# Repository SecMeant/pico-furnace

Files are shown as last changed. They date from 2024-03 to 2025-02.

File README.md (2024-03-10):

# pico-furnace
Raspberry PI pico wireless controller for electric furnace.

# Building

## Dependencies
 - [pico sdk](https://github.com/raspberrypi/pico-sdk) (tested on tag: 1.5.1)
 - [pico extras](https://github.com/raspberrypi/pico-extras) (tested on tag: sdk-1.5.1)

## Configure project options

Create `.config` with values for all CONFIG_* variables that user is intrested in changing.
User can also use one of the predefined config files from `configs/` by copying one of the files into `.config` file.
Configuring a project for the typical furnace target would look like:
```
cp configs/furnace .config
```
Make sure you always `make clean` after changing `.config` file to make sure new options are used to build the project.

## Configure wlan options

Create `wlan.ini` file and fill SSID and password of the WiFi network to which pico should connect when booting.
Example contents of the file:
```
ssid=my_wifi_network_name
pass=super_secret_password
```

## Configure and build

```console
export PICO_SDK_PATH=<path to pico sdk>
export PICO_EXTRAS_PATH=<path to pico extras>
make
```

## Flashing the binary

Connect pico W board USB while pressing the boot button and run:

```console
make flash
```

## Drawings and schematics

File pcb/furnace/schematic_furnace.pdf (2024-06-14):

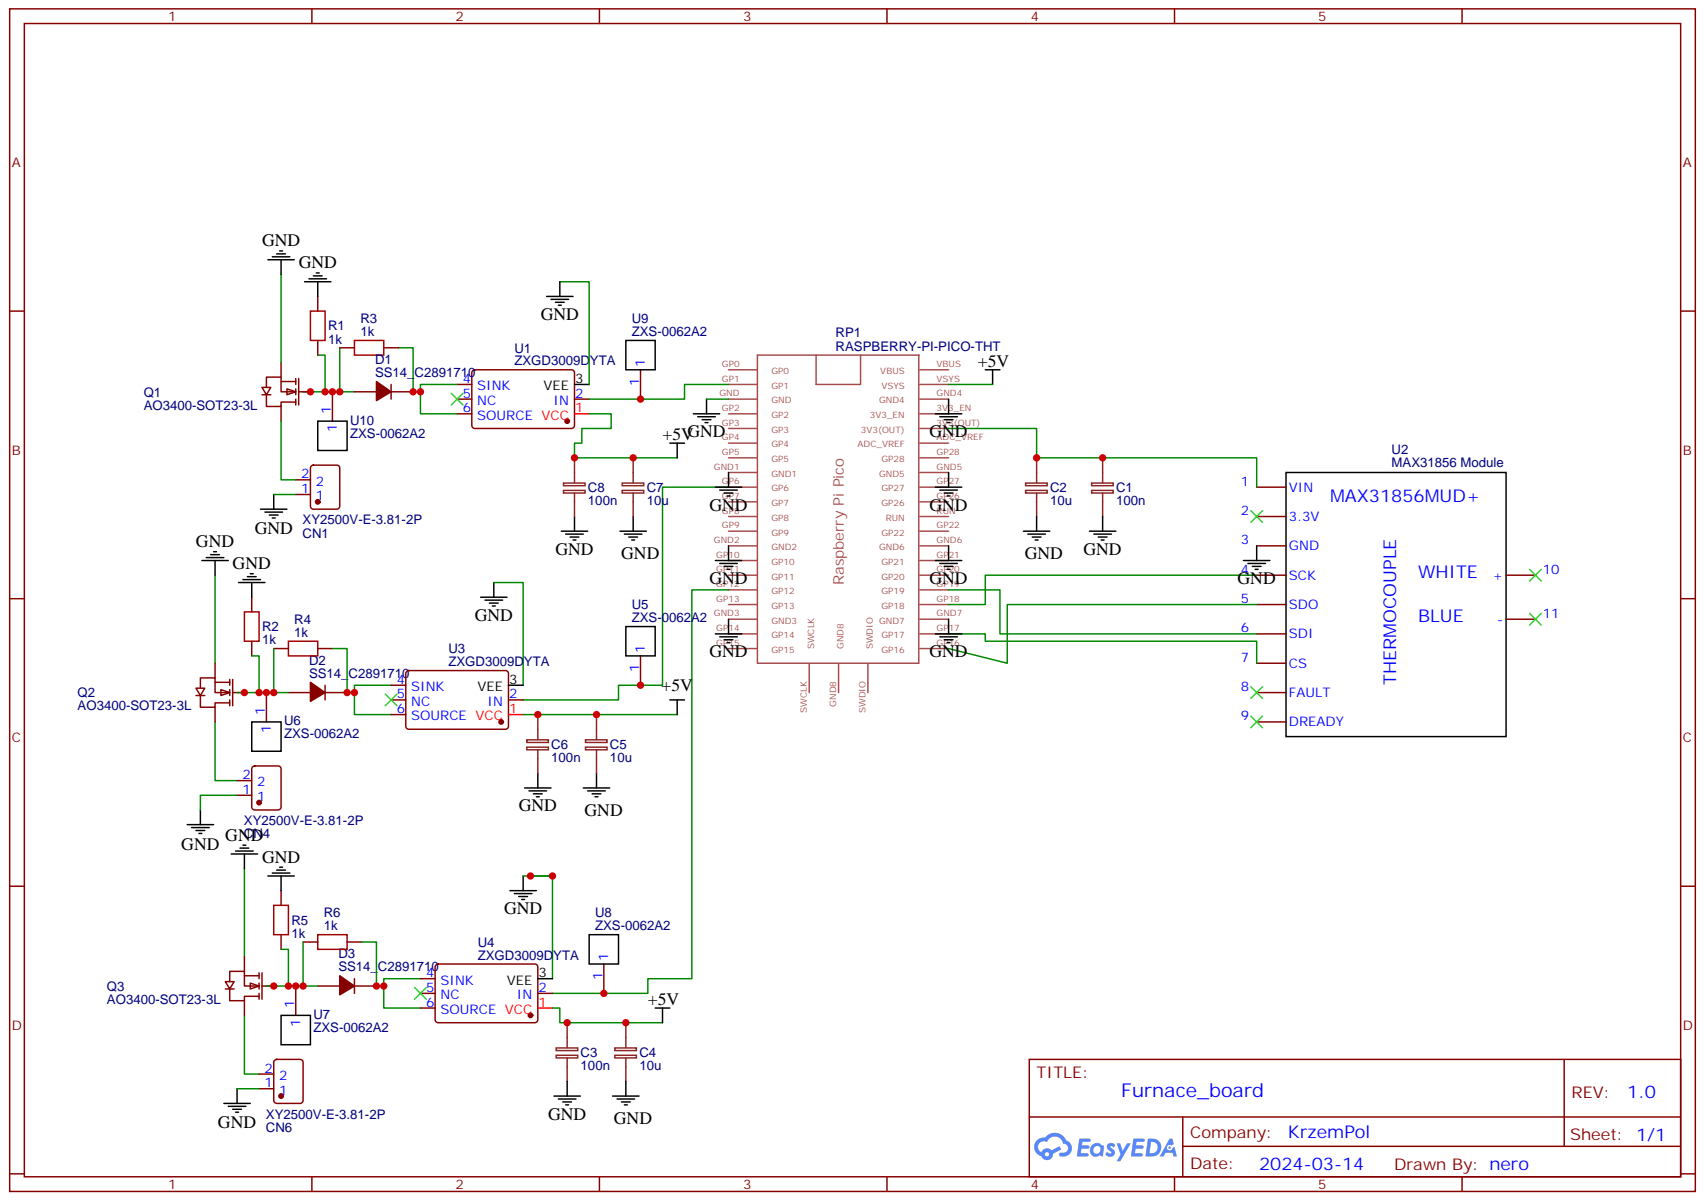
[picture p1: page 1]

RASPBERRY-PI-PICO-THT

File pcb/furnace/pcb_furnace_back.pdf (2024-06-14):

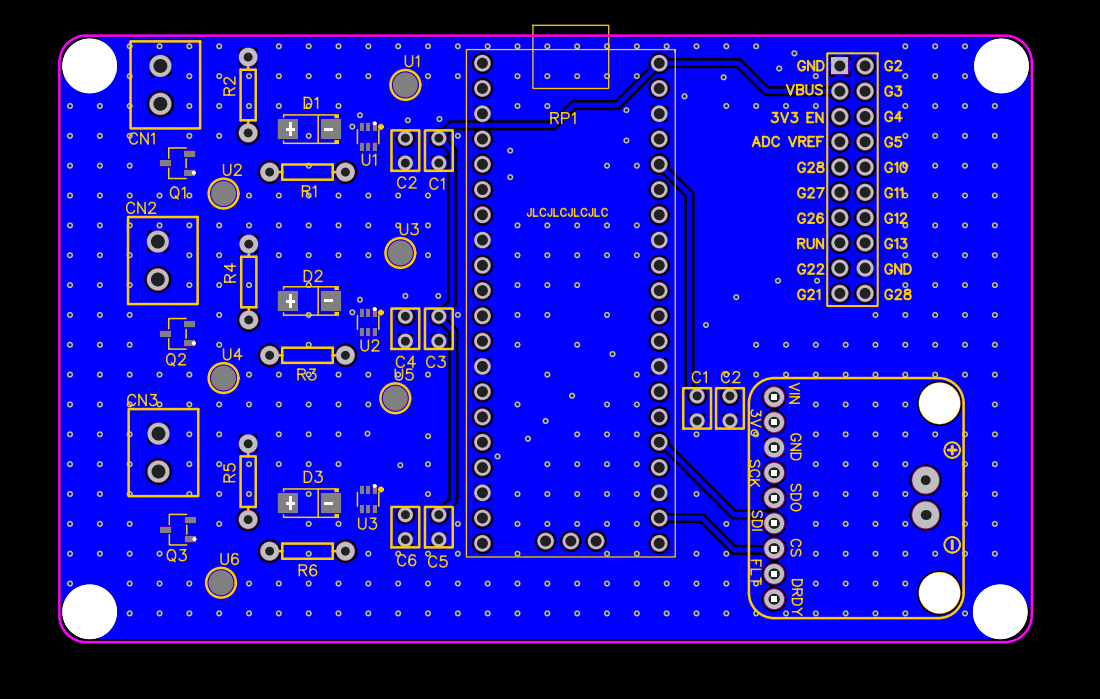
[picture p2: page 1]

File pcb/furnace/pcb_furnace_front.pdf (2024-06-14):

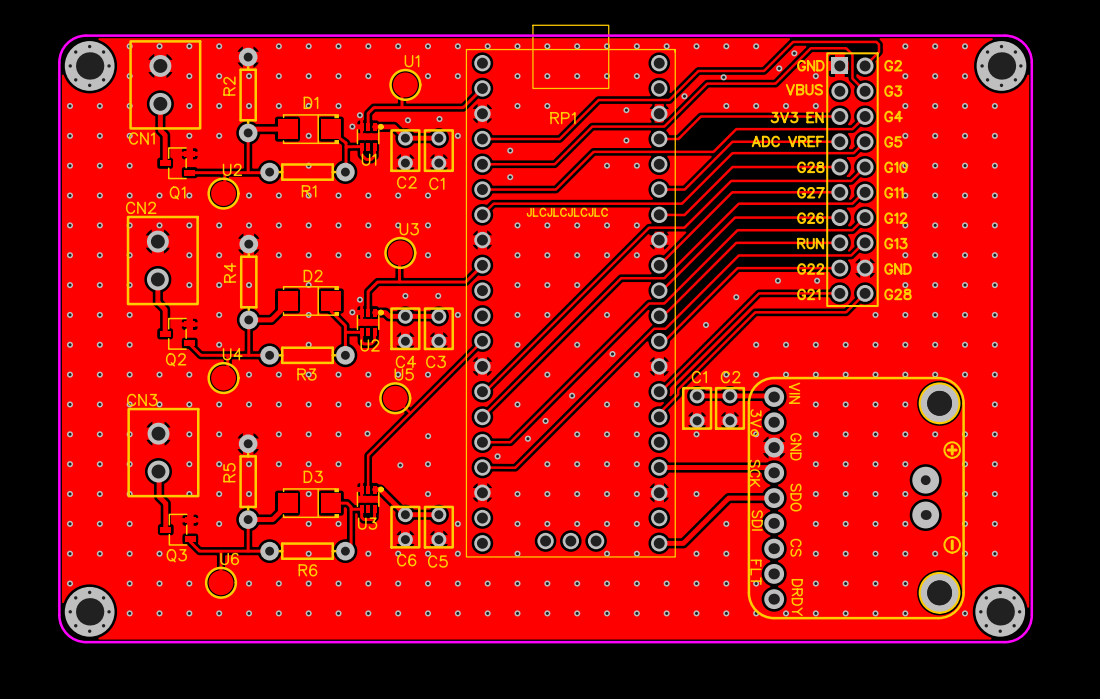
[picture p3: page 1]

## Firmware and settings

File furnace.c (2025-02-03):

#include <time.h>
#include <stdlib.h>
#include <string.h>

#include "pico/bootrom.h"
#include "pico/cyw43_arch.h"
#include "pico/stdlib.h"

#include "hardware/spi.h"

#include "lwip/pbuf.h"
#include "lwip/tcp.h"

#include "spi_config.h"
#if CONFIG_THERMO
  #include "max318xx.h"
#endif
#include "logger.h"

#if CONFIG_FLASH
  #include "flash_io.h"
#endif

#include "common.h"
#include CONSTEVAL_HEADER

#define TCP_PORT        4242
#define DEBUG_printf    printf


/* GPIO for enabling and disabling heating of the furnace. */
#define FURNACE_FIRE_PIN CONFIG_FURNACE_FIRE_PIN
#define FURNACE_FIRE_PWM_SLICE pwm_gpio_to_slice_num(FURNACE_FIRE_PIN)
#define FURNACE_FIRE_PWM_CHANNEL pwm_gpio_to_channel(FURNACE_FIRE_PIN)

#if CONFIG_SHUTTER
  #include "shutter.c"
#endif

#include "target.h"

#if CONFIG_WATER
  #define WATER_PIN 9
  #define WATER_PIN_SLICE pwm_gpio_to_slice_num(WATER_PIN)
#endif

#include "pwm.c"

#if CONFIG_MAGNETRON
  #include "magnetron.c"
#endif

int
max318xx_init(void);

static err_t
tcp_server_close(furnace_context_t* ctx)
{
  err_t err = ERR_OK;

  if (ctx->tcp.client_pcb != NULL) {
    tcp_arg(ctx->tcp.client_pcb, NULL);
    tcp_recv(ctx->tcp.client_pcb, NULL);
    tcp_err(ctx->tcp.client_pcb, NULL);
    err = tcp_close(ctx->tcp.client_pcb);

    if (err != ERR_OK) {
      log_stdout_server(ctx->log_bits, "close failed %d, calling abort\n", err);
      tcp_abort(ctx->tcp.client_pcb);
      err = ERR_ABRT;
    }

    ctx->tcp.client_pcb = NULL;
  }

  if (ctx->tcp.server_pcb) {
    tcp_arg(ctx->tcp.server_pcb, NULL);
    tcp_close(ctx->tcp.server_pcb);
    ctx->tcp.server_pcb = NULL;
  }

  return err;
}

static err_t
tcp_server_send_data(furnace_context_t* ctx,
                     struct tcp_pcb*    tpcb,
                     const uint8_t*     data,
                     u16_t              size)
{
  return tcp_write(tpcb, data, size, TCP_WRITE_FLAG_COPY);
}

static void
tcp_server_recv_(furnace_context_t *ctx, struct tcp_pcb* tpcb, struct pbuf* p)
{
  log_stdout_server(ctx->log_bits, "tcp_server_recv %d\n", p->tot_len);

  if (p->tot_len == 0)
    return;

  /*
   * Receive the buffer
   *
   * TODO: We should probably call pbuf_copy_partial in a loop
   *       to make sure we receive everything.
   */
  const uint16_t buffer_left = BUF_SIZE;
  ctx->tcp.recv_len =
    pbuf_copy_partial(p, ctx->tcp.recv_buffer, p->tot_len > buffer_left ? buffer_left : p->tot_len, 0);
  tcp_recved(tpcb, p->tot_len);
}

#if CONFIG_WATER
static void
handle_command_water(furnace_context_t* ctx, void (*feedback)(const char *, const size_t), unsigned arg) {
    const int res = set_pwm_safe(WATER_PIN, ctx, arg);

    if(res == 0)
      return;

    if (res  == 1){
      const char msg[] = "water pwm argument too big!\r\n";
      const size_t msg_len = sizeof(msg)-1;
      feedback(msg, msg_len);
      return;
    }

    if(res == -1){
      const char msg[] = "set_pwm_safe: unexpected pin argument!\r\n";
      const size_t msg_len = sizeof(msg)-1;
      feedback(msg, msg_len);
      return;
    }

    const char msg[] = "set_pwm_safe: unexpected return value!\r\n";
    const size_t msg_len = sizeof(msg)-1;
    feedback(msg, msg_len);
}
#endif

static int
set_max_pwm_safe(furnace_context_t *ctx, int new_max_pwm)
{
    if (new_max_pwm > MAX_PWM)
      return 1;

    if (ctx->pwm_level > new_max_pwm)
      ctx->pwm_level = new_max_pwm;

    ctx->ceiling_pwm = new_max_pwm;

    return 0;
}

#if CONFIG_STIRRER
static void
set_stirrer(bool opt)
{
  gpio_put(STIRRER_PIN, opt);
}
#endif

static void
command_handler(furnace_context_t* ctx, uint8_t* buffer, void (*feedback)(const char*, const size_t))
{
  unsigned arg;
  char     str_arg[BUF_SIZE];

  if (buffer[0] == '\n') return;

  if (memcmp(buffer, "reboot", 6) == 0) {
    reset_usb_boot(0,0);
  } else if (sscanf(buffer, "max_pwm %u", &arg) == 1) {
    const int res = set_max_pwm_safe(ctx, arg);
    if (res == 1) {
      const char msg[] = "pwm argument too big!\r\n";
      const size_t msg_len = sizeof(msg)-1;
      feedback(msg, msg_len);
    }
  } else if (strncmp(buffer, "pwm\n", 4) == 0) {
      char msg[16];
      const size_t msg_len = snprintf(msg, sizeof(msg), "pwm = %d\r\n", ctx->pwm_level);
      feedback(msg, msg_len);
  } else if (sscanf(buffer, "pwm %u", &arg) == 1) {
    const int res= set_pwm_safe(FURNACE_FIRE_PIN, ctx, arg);
    if (res == 0){
#if CONFIG_AUTO == CONFIG_AUTO_PILOT || CONFIG_AUTO == CONFIG_AUTO_MAPPER
      ctx->pilot.is_enabled = 0;
#endif
    } else if ( res == 1){
      const char msg[] = "pwm argument too big!\r\n";
      const size_t msg_len = sizeof(msg)-1;
      feedback(msg, msg_len);
    } else if ( res == -1){
      const char msg[] = "set_pwm_safe: unexpected pin argument!\r\n";
      const size_t msg_len = sizeof(msg)-1;
      feedback(msg, msg_len);
    } else {
      const char msg[] = "set_pwm_safe: unexpected return value!\r\n";
      const size_t msg_len = sizeof(msg)-1;
      feedback(msg, msg_len);
    }
  }
#if CONFIG_AUTO == CONFIG_AUTO_PILOT
  else if (strncmp(buffer, "auto\n", 5) == 0) {
      char msg[16];
      const size_t msg_len = snprintf(msg, sizeof(msg), "auto = %d\r\n", ctx->pilot.is_enabled);
      feedback(msg, msg_len);
  } else if (sscanf(buffer, "auto %u", &arg) == 1) {
    if (arg > 1) {
      const char msg[] = "auto argument needs to be 0 or 1\r\n";
      const size_t msg_len = sizeof(msg)-1;
      feedback(msg, msg_len);
    } else {
      ctx->pilot.is_enabled = arg;
    }
  } else if (sscanf(buffer, "temp %u", &arg) == 1) {
    if (arg > MAX_TEMP) {
      const char msg[] = "temp argument too big!\r\n";
      const size_t msg_len = sizeof(msg)-1;
      feedback(msg, msg_len);
    } else {
      ctx->pilot.des_temp = arg;
    }
  } else if (strncmp(buffer, "temp\n", 5) == 0) {
    char msg[16];
    const size_t msg_len = snprintf(msg, sizeof(msg), "temp = %d\r\n", ctx->pilot.des_temp);
    feedback(msg, msg_len);
  }
#endif
  else if (sscanf(buffer, "log %" STR(BUF_SIZE) "s %u", &str_arg, &arg) == 2) {
    if(arg >= 2) {
      const char msg[] = "log value too big!\r\n";
      const size_t msg_len = sizeof(msg)-1;
      feedback(msg, msg_len);
    } else {
      set_log(str_arg, arg, &ctx->log_bits);
    }
  } else if (strncmp(buffer, "log\n", 4) == 0) {
    char msg[LOG_MSG_BUFFER_SIZE];
    const size_t msg_len = get_logs(msg, ctx->log_bits);
    feedback(msg, msg_len);
  } else if(memcmp(buffer, "help\n", 5) == 0) {

    const char msg[] = "help              \t\t shows this message\n"
                        "reboot            \t\t reboot device\n"
                        "pwm <0;50>        \t\t sets pwm\n"
                        "pwm               \t\t prints current pwm level\n"
                        "max_pwm <0;50>    \t\t sets max pwm level.\n"
                        "                  \t\t\t Device will never exceed this pwm value\n"
#if CONFIG_THERMO && CONFIG_AUTO == CONFIG_AUTO_PILOT
                        "temp <0;" STR(MAX_TEMP) ">     \t\t sets wanted temperature\n"
                        "temp              \t\t shows current wanted temperature\n"
                        "auto <0;1>        \t\t sets automatic pwm control, it is\n"
                        "                  \t\t reaching temperature set by 'temp' command\n"
                        "                  \t\t\t 0 - off\n"
                        "                  \t\t\t 1 - on\n"
                        "auto              \t\t shows current auto status\n"
#endif
#if CONFIG_MAGNETRON
                        "pulse <0:127>     \t\t starts pulses of magnetron\n"
#endif
#if CONFIG_WATER
                        "water <0:10>      \t\t sets pwm duty of water channel\n"
                        "water             \t\t shows current water pwm\n"
#endif
#if CONFIG_AUTO == CONFIG_AUTO_MAPPER
                        "map <0;1>         \t\t sets automatic pwm mapping, it is\n"
                        "                  \t\t checking max temperature on every pwm\n"
                        "                  \t\t\t 0 - off\n"
                        "                  \t\t\t 1 - on\n"
                        "map               \t\t shows current map status\n"
#endif
#if CONFIG_STIRRER
                        "stir <0;1>        \t\t turns on the stirring cap for beaker\n"
                        "                  \t\t\t 0 - off\n"
                        "                  \t\t\t 1 - on\n"
#endif
                        "log <option> <0;1>\t\t sets output level on stdio\n"
                        "                  \t\t\t options:\n"
                        "                  \t\t\t\t server,\n"
                        "                  \t\t\t\t thermocouple,\n"
                        "                  \t\t\t\t basic\n"
                        "                  \t\t\t 0 - off\n"
                        "                  \t\t\t 1 - on\n"
                        "log               \t\t prints names of turned on log options\n";
    const size_t msg_len = sizeof(msg)-1;
    feedback(msg, msg_len);
  }
#if CONFIG_MAGNETRON
  else if(sscanf(buffer, "pulse %u", &arg) == 1) {
    if(arg > 127){
      const char msg[] = "pulse value too big!\r\n";
      const size_t msg_len = sizeof(msg)-1;
      feedback(msg, msg_len);
    } else {
      ctx->pulse_count = arg*2;
    }
  }
#endif
#if CONFIG_WATER
  else if(sscanf(buffer, "water %u", &arg) == 1) {
    handle_command_water(ctx, feedback, arg);
  } else if(memcmp(buffer, "water\n", 6) == 0){
    char msg[16];
    const size_t msg_len = snprintf(msg, sizeof(msg), "water = %d\r\n", ctx->pwm_water);
    feedback(msg, msg_len);
  }
#endif
#if CONFIG_SHUTTER
  else if(sscanf(buffer, "shutter %u", &arg) == 1){
    if(arg > MAX_SHUTTER_MS){
      const char msg[] = "time argument too big !!!\r\n";
      const size_t msg_len = sizeof(msg)-1;
      feedback(msg, msg_len);
    } else if(ctx->shutter.time_ms == 0){
      ctx->shutter.time_ms = arg;
    } else{
      const char msg[] = "shutter already in work \n";
      const size_t msg_len = sizeof(msg)-1;
      feedback(msg, msg_len);
    }
  } else if(sscanf(buffer, "shutter %s", str_arg) == 1) {
    if(strncmp(str_arg, "on", 2) == 0){
      ctx->shutter.time_ms = 1;
      ctx->shutter.intern_state = SHUTTER_ON_OPTION;
    }else if((strncmp(str_arg, "off", 3) == 0)){
      ctx->shutter.time_ms = 1;
      ctx->shutter.intern_state = SHUTTER_OFF_OPTION;
    }
  }
#endif
#if CONFIG_AUTO == CONFIG_AUTO_MAPPER
  else if(sscanf(buffer, "map %u", &arg) == 1) {
    if(arg > 1){
      const char msg[] = "map argument needs to be 0 or 1\r\n";
      const size_t msg_len = sizeof(msg)-1;
      feedback(msg, msg_len);
    } else {
      if(ctx->cur_temp >= 40){
        const char msg[] = "map can be started only at temperatures lower than 40\r\n";
        const size_t msg_len = sizeof(msg)-1;
        feedback(msg, msg_len);
      } else {
        ctx->pwm_level = 0;
        ctx->pilot.is_enabled = false;
        ctx->mapper.is_enabled = arg;
      }
    }
  } else if(strncmp(buffer, "map\n", 4) == 0) {
      char msg[16];
      const size_t msg_len = snprintf(msg, sizeof(msg), "map = %d\r\n", ctx->mapper.is_enabled);
      feedback(msg, msg_len);
  }
#endif
#if CONFIG_STIRRER
  else if(sscanf(buffer, "stir %u", &arg) == 1){
    if(arg > 1){
      const char msg[] = "stir argument needs to be 0 or 1\r\n";
      const size_t msg_len = sizeof(msg)-1;
      feedback(msg, msg_len);
    } else {
      set_stirrer((bool) arg);
    }
  }
#endif
}

static void
tcp_command_handler(furnace_context_t* ctx, struct tcp_pcb* tpcb)
{
  void
  send(const char* msg, const size_t msg_len)
  {
    tcp_server_send_data(ctx, tpcb, msg, msg_len);
  }

  command_handler(ctx, ctx->tcp.recv_buffer, &send);
}

static err_t
tcp_server_recv(void* ctx_, struct tcp_pcb* tpcb, struct pbuf* p, err_t err)
{
  furnace_context_t *ctx = (furnace_context_t*)ctx_;

  if (!p) {
    tcp_server_close(ctx);
    return err;
  }

  tcp_server_recv_(ctx, tpcb, p);
  //We are expecting only strings, we can manually terminate the string
  ctx->tcp.recv_buffer[p->tot_len] = '\0';

  pbuf_free(p);

  // Echo back for debugging
  // tcp_server_send_data(ctx, tpcb, ctx->recv_buffer, ctx->recv_len);

  tcp_command_handler(ctx, tpcb);

  log_stdout_server(ctx->log_bits, "tcp_server_recv: %.*s\n", p->tot_len, ctx->tcp.recv_buffer);

  return ERR_OK;
}

static void
tcp_server_err(void* ctx_, err_t err)
{
  furnace_context_t *ctx = (furnace_context_t*)ctx_;

  log_stdout_server(ctx->log_bits, "tcp_client_err_fn %d\n", err);
  tcp_server_close(ctx);
}

static err_t
tcp_server_accept(void* ctx_, struct tcp_pcb* client_pcb, err_t err)
{
  furnace_context_t *ctx = (furnace_context_t*)ctx_;

  if (err != ERR_OK || client_pcb == NULL) {
    log_stdout_server(ctx->log_bits, "Failure in accept\n");
    tcp_server_close(ctx);
    return ERR_VAL;
  }

  log_stdout_server(ctx->log_bits, "Client connected\n");

  ctx->tcp.client_pcb = client_pcb;
  tcp_arg(client_pcb, ctx);
  tcp_recv(client_pcb, tcp_server_recv);
  tcp_err(client_pcb, tcp_server_err);

  client_pcb->so_options |= SOF_KEEPALIVE;
  client_pcb->keep_intvl = 4000; /* 4 seconds */

  return ERR_OK;
}

static bool
tcp_server_open(void* ctx_)
{
  furnace_context_t *ctx = (furnace_context_t*)ctx_;

  log_stdout_server(ctx->log_bits,
                     "Starting server at %s on port %u\n",
                     ip4addr_ntoa(netif_ip4_addr(netif_list)),
                     TCP_PORT);

  struct tcp_pcb* pcb = tcp_new_ip_type(IPADDR_TYPE_ANY);
  if (!pcb) {
    log_stdout_server(ctx->log_bits, "Failed to create pcb\n");
    return false;
  }

  err_t err = tcp_bind(pcb, NULL, TCP_PORT);
  if (err) {
    log_stdout_server(ctx->log_bits, "Failed to bind to port %u\n", TCP_PORT);
    return false;
  }

  ctx->tcp.server_pcb = tcp_listen_with_backlog(pcb, 1);
  if (!ctx->tcp.server_pcb) {
    log_stdout_server(ctx->log_bits, "Failed to listen\n");
    if (pcb) {
      tcp_close(pcb);
    }
    return false;
  }

  tcp_arg(ctx->tcp.server_pcb, ctx);
  tcp_accept(ctx->tcp.server_pcb, tcp_server_accept);

  return true;
}

static void
do_thermocouple_work(furnace_context_t *ctx, bool deadline_met)
{
  if (!deadline_met)
    return;

#if CONFIG_THERMO
  ctx->cur_temp = max318xx_read_temperature();
#endif
#if CONFIG_THERMO == CONFIG_THERMO_KTYPE
  log_stdout_thermocouple(ctx->log_bits, "cold: %u\n", max318xx_read_cold_junction());
#endif
  log_stdout_thermocouple(ctx->log_bits, "hot: %u\n", ctx->cur_temp);
}

static int
format_status(char* buffer, furnace_context_t* ctx)
{
#if CONFIG_AUTO == CONFIG_AUTO_NONE
  return snprintf(
      buffer,
      FORMAT_STATUS_AUTO_NONE_SIZE,
      FORMAT_STATUS_AUTO_NONE,
      ctx->cur_temp,
      ctx->pwm_level,
      MAX_PWM
      );
#else
    return snprintf(
      buffer,
      FORMAT_STATUS_AUTO_PILOT_SIZE,
      FORMAT_STATUS_FMT,
      ctx->cur_temp,
      ctx->pilot.des_temp,
      ctx->pwm_level,
      ctx->ceiling_pwm,
      MAX_PWM,
      ctx->pilot.is_enabled
    );
#endif
}

#if CONFIG_AUTO == CONFIG_AUTO_MAPPER

static int
format_mapper(char *buffer, furnace_context_t *ctx)
{
    return snprintf(
      buffer,
      MAPPER_STATUS_SIZE,
      MAPPER_STATUS_FMT,
      ctx->pwm_level,
      ctx->mapper.max_pwm_temp
    );
}

#endif

static void
do_tcp_work(furnace_context_t *ctx, bool deadline_met)
{
#if CONFIG_AUTO == CONFIG_AUTO_NONE
  char temperature_str[FORMAT_STATUS_AUTO_NONE_SIZE];
#else
  char temperature_str[FORMAT_STATUS_AUTO_PILOT_SIZE];
#endif

  cyw43_arch_poll();

  // If disconnected, reset and setup listening
  if (ctx->tcp.server_pcb == NULL || ctx->tcp.server_pcb->state == CLOSED) {
    memset(&ctx->tcp, 0, sizeof(ctx->tcp));
    if (!tcp_server_open(ctx)) {
      tcp_server_close(ctx);
    }
  }

  if (ctx->tcp.client_pcb && deadline_met) {
    const int temperature_str_len = format_status(temperature_str, ctx);

    tcp_server_send_data(
      ctx,
      ctx->tcp.client_pcb,
      (uint8_t*)temperature_str,
      temperature_str_len
    );
  }

}

static inline int
sgn(int val_1, int val_2)
{
  if(val_1 > val_2)
    return -1;
  return 1;
}

static inline uint8_t
clamp_u8(int min, int max, int val)
{
  uint8_t value = (uint8_t)val;

  if(val < min)
    value = min;

  if(val > max)
    value = max;

  return value;
}

static void
init_furnace(furnace_context_t *ctx)
{
  memset(ctx, 0, sizeof(*ctx));

  ctx->ceiling_pwm = MAX_PWM;
}

#if CONFIG_AUTO == CONFIG_AUTO_PILOT || CONFIG_AUTO == CONFIG_AUTO_MAPPER
static void
do_pilot_work(furnace_context_t *ctx)
{
  if (!ctx->pilot.is_enabled)
    return;

  const bool deadline_met = get_absolute_time() > ctx->pilot.pilot_deadline;

  if (!deadline_met)
    return;

  const int min_increase_rate = 1;
  const int diff = ctx->cur_temp - ctx->pilot.last_temp;
  const int sign = sgn(ctx->cur_temp, ctx->pilot.des_temp);
  unsigned pwm = ctx->pwm_level;

  ctx->pilot.last_temp = ctx->cur_temp;
  ctx->pilot.pilot_deadline = make_timeout_time_ms(CONFIG_FURNACE_DEADLINE_MS);

  /*
   * If going in the wrong direction
   * or going in the good direction,
   * but slowly - nudge the PWM.
   */
  if(sign*diff <= min_increase_rate)
    pwm += sign;

  set_pwm_safe(FURNACE_FIRE_PIN, ctx, pwm);
}

static void
init_pilot(furnace_context_t *ctx)
{
  ctx->pilot.des_temp = 0;
  ctx->pilot.last_temp = 0;
  ctx->pilot.is_enabled = false;
}
#endif

#if CONFIG_STIRRER
static void
init_stirrer(void)
{
  gpio_init(STIRRER_PIN);
  gpio_set_dir(STIRRER_PIN, GPIO_OUT);
}
#endif

static void
init_stdio(furnace_context_t* ctx)
{
  ctx->stdio.parser = ctx->stdio.buffer;
  memset(&ctx->stdio.buffer, 0, BUF_SIZE);
}

static void
reset_stdio_data(furnace_context_t* ctx)
{
  memset(&ctx->stdio.buffer, 0, BUF_SIZE);
  ctx->stdio.parser = ctx->stdio.buffer;
}

static void
stdio_command_handler(furnace_context_t* ctx)
{
  void
  send_stdio(const char* msg, const size_t msg_len)
  {
    if(msg_len == 0) return;
    printf(msg);
  }

  command_handler(ctx, ctx->stdio.buffer, &send_stdio);
}

static void
do_stdio_work(furnace_context_t* ctx, bool deadline_met)
{
  if(deadline_met)
  {
    char buffer[FORMAT_STATUS_AUTO_PILOT_SIZE];

    format_status(buffer, ctx);
    log_stdout_basic(ctx->log_bits, buffer);
  }

  while(1) {
    uint8_t c = getchar_timeout_us(0);

    if(c == (uint8_t) PICO_ERROR_TIMEOUT) return;

    if(ctx->stdio.parser == ctx->stdio.buffer + BUF_SIZE){
      printf("\nLines longer than %d are invalid!\nResetting stdio buffer.\n", BUF_SIZE);
      reset_stdio_data(ctx);
      return;
    }

    // User may change last sent character from lf to cr, vice versa or crlf
    // Although, in parsing command, we do not care how user sent this
    // and we are always putting '\n' at the end of command
    if(c == '\n' || c == '\r') {
      *ctx->stdio.parser = '\n';
      stdio_command_handler(ctx);
      reset_stdio_data(ctx);
      return;
    }

    *ctx->stdio.parser = c;
    ctx->stdio.parser++;
  }
}

#if CONFIG_AUTO == CONFIG_AUTO_MAPPER

static void
mapper_deadline__(furnace_context_t *ctx)
{
  if(ctx->cur_temp > ctx->mapper.max_pwm_temp){
    ctx->mapper.max_pwm_temp = ctx->cur_temp;
    return;
  }

  char buffer[MAPPER_STATUS_SIZE];

  const int size = format_mapper(buffer, ctx);
  tcp_server_send_data(
    ctx,
    ctx->tcp.client_pcb,
    (uint8_t*)buffer,
    size
  );

  const unsigned pwm = ctx->pwm_level + 1;

  const int res = set_pwm_safe(FURNACE_FIRE_PIN, ctx, pwm);

  if( res == -1 ) {
    const char msg[] = "set_pwm_safe: unexpected pin argument!\r\n";
    const size_t msg_len = sizeof(msg)-1;
    tcp_server_send_data(
      ctx,
      ctx->tcp.client_pcb,
      (uint8_t*)buffer,
      size
    );
  } else if ( res == 1 ) {
    const char msg[] = "pwm_level has reached MAX_PWM, enabling auto and steering temp towards FALLBACK_TEMP!\r\n";
    const size_t msg_len = sizeof(msg)-1;
    tcp_server_send_data(
      ctx,
      ctx->tcp.client_pcb,
      (uint8_t*)buffer,
      size
    );

    ctx->mapper.is_enabled = false;
    ctx->pilot.is_enabled = true;
    ctx->pilot.des_temp = FALLBACK_TEMP;
  }
}

static void
mapper_deadline_(furnace_context_t *ctx)
{
  mapper_deadline__(ctx);
  ctx->mapper.deadline = make_timeout_time_ms(PWM_MAPPER_MINUTES * 60 * 1000);
}

static void
mapper_maxtemp_reached_(furnace_context_t *ctx)
{
  const char msg[] = "cur_temp has reached MAX_TEMP, enabling auto and steering temp towards FALLBACK_TEMP!\r\n";
  const size_t msg_len = sizeof(msg)-1;
  tcp_server_send_data(
    ctx,
    ctx->tcp.client_pcb,
    (uint8_t*)msg,
    msg_len
  );

  ctx->mapper.is_enabled = false;
  ctx->pilot.is_enabled = true;
  ctx->pilot.des_temp = FALLBACK_TEMP;
}

static void
do_mapper_work(furnace_context_t *ctx)
{
  if(!ctx->mapper.is_enabled)
    return;

  if(ctx->cur_temp >= MAX_TEMP)
    return mapper_maxtemp_reached_(ctx);

  const bool deadline_met = get_absolute_time() > ctx->mapper.deadline;
  if (deadline_met)
    return mapper_deadline_(ctx);
}

#endif

static int
main_work_loop(void)
{
  furnace_context_t* ctx;

  ctx = malloc(sizeof(*ctx));

  if (!ctx) {
    return 1;
  }

  init_pwm();
  init_furnace(ctx);
#if CONFIG_AUTO == CONFIG_AUTO_MAPPER || CONFIG_AUTO == CONFIG_AUTO_PILOT
  init_pilot(ctx);
#endif
  init_stdio(ctx);

#if CONFIG_MAGNETRON
  init_magnetron(ctx);
#endif

#if CONFIG_STIRRER
  init_stirrer();
#endif

#if CONFIG_FLASH
  init_flash(ctx);
#endif

  cyw43_arch_gpio_put(CYW43_WL_GPIO_LED_PIN, 1);

  while (1) {
    const absolute_time_t now = get_absolute_time();
    const bool deadline_met = now > ctx->update_deadline;
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
int
main(void)
{
  stdio_init_all();

  if (cyw43_arch_init()) {
    DEBUG_printf("failed to initialise\n");
    return 1;
  }

  cyw43_arch_gpio_put(CYW43_WL_GPIO_LED_PIN, 0);
  cyw43_arch_enable_sta_mode();

  while(1) {
    int ret = main_();

    if (ret)
      DEBUG_printf("main() failed with %d\n", ret);

    sleep_ms(3000);
  }
}

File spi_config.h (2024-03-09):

#pragma once

#define FURNACE_SPI_RX_PIN    16
#define FURNACE_SPI_CSN_PIN   17
#define FURNACE_SPI_SCK_PIN   18
#define FURNACE_SPI_TX_PIN    19

#define FURNACE_SPI_INSTANCE spi0

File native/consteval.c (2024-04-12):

#include <stdio.h>

#include "common.h"

static void
prepare(FILE* fptr)
{
  fprintf(fptr, "#pragma once\n\n");
}

static void
calculate_status_size(FILE* fptr)
{
  const size_t size = snprintf(0, 0, FORMAT_STATUS_FMT, MAX_TEMP, MAX_TEMP, MAX_PWM, MAX_PWM, MAX_PWM, MAX_AUTO) + 1;
  fprintf(fptr, "#define FORMAT_STATUS_AUTO_PILOT_SIZE %u\n", size);
}

#if CONFIG_AUTO == CONFIG_AUTO_MAPPER
static void
calculate_mapper_size(FILE* fptr)
{
  const size_t size = snprintf(0, 0, MAPPER_STATUS_FMT, MAX_PWM, MAX_TEMP) + 1;
  fprintf(fptr, "#define MAPPER_STATUS_SIZE %u\n", size);
}
#endif

#if CONFIG_AUTO == CONFIG_AUTO_NONE
static void
calculate_none_size(FILE* fptr)
{
  const size_t size = snprintf(0, 0, FORMAT_STATUS_AUTO_NONE, MAX_TEMP, MAX_PWM, MAX_PWM) + 1;
  fprintf(fptr, "#define FORMAT_STATUS_AUTO_NONE_SIZE %u\n", size);
}
#endif


int
main()
{
  FILE* fptr = fopen(CONSTEVAL_HEADER, "w");
  prepare(fptr);
  calculate_status_size(fptr);
#if CONFIG_AUTO == CONFIG_AUTO_MAPPER
  calculate_mapper_size(fptr);
#endif
#if CONFIG_AUTO == CONFIG_AUTO_NONE
  calculate_none_size(fptr);
#endif
  fclose(fptr);
}

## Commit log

2023-09-04 Basic SPI setup
2023-09-06 Replacing printf with DEBUG_printf
2023-09-06 Reboot into BOOTSEL on "reboot" received on TCP
    [furnace.c]
2023-09-06 Remove tcp_server_sent callback and simplify tcp_server_send_data
    We don't really use the first one. It's useful mostly in case of waiting
    for space to be freed from tcp send buffer.
    In case of the second one, we don't really care what was the error - we
    just terminate in case of any error.
    [furnace.c]
2023-09-08 Add SPI initialization for max31856 thermocouple
2023-09-08 Adding max31856 spi initialization code
    MAX31856 - Precision Thermocouple to Digital Converter with Linearization.
    Docs: https://holzcoredump.cc/MAX31856.pdf
2023-09-10 Separating max31856 driver into header and C source
2023-09-10 Moving initialization of hardware out of the main work loop
    Calling initialization code twice causes a assert failure, thats why we
    now just execute it once, after the boot and when doing warm restart, we
    skip it.
    [furnace.c]
2023-09-10 Adding pin configuration for driving SSR (enabling/disabling heating)
2023-09-10 Lowering wifi connect timeout from 30s to 5s
    We experienced 30s timeout is too long in practice.
    [furnace.c]
2023-09-10 max31856: Fix SPI configuration, add correct CPOL and CPHA config
    CPOL = 0 and CPHA = 1 is needed for writes to work. Otherwise max31856
    was missing our first bit of transmission when doing the writes.
    [spi.c]
2023-09-10 Add PWM implementation for heating
2023-09-10 Replace mock/fake temperature reading with a real one
    [furnace.c]
2023-11-17 pwm command without parameter now returns current value via tcp
2023-11-17 Make PWM frequency higher.
    Now we divide 1 millisecond into 15 equal chunks instead of 5 minutes.
    This should put much less stress on the resistance wire, but otherwise
    have the same heating effect.
2024-01-03 Automatic pwm steering
    We would like the system to be as autonomous as it can be.
    Autosteer provided in this commit checks if the temperature during last 15
    seconds has stabilized, and if it stabilized, pwm is driven higher or lower
    depending on desired temperature. 15 second time period has been chosen
    based on experience in furnace heating.
    [furnace.c]
2024-01-03 Bug fix, no string terminator while receiving via tcp
    We do not expect any data type other than string, so we can terminate
    the string received. Not terminating the string caused bug which resulted
    in wrong program behaviour.
    [furnace.c]
2024-01-04 Disable autopilot mode when setting pwm by user
    We would like autopilot mode to turn off when user sets
    new pwm.
2024-01-04 Change pwm pulse time to 1023, and chunk count to 31
2024-01-04 Add communication over stdio via usb
    Now user can communicate with device via usb.
2024-01-05 Replace software based PWM with a hardware one
    Saves CPU time, has better characteristics and requires less code.
    [furnace.c, pwm.c]
2024-01-05 command_handler: add missing pilot disabling when PWM level is set manually
    [furnace.c]
2024-01-05 Improve autopilot trend detection steering
    Earlier policy would first wait for temperature to stabilize,
    which might have caused overheating before steering the temperature
    lower.
    [furnace.c]
2024-01-06 Remove workaround for PWM_MAX smoothing
    Pico's PWM driver has this weird behavior of going down to 0V when close
    to wrapping. Earlier we had a *very smart* way for dealing with it in
    software, but it turns out It doesn't always work and we observed it
    going down to 0V sometimes.
    For now we don't care about the small drop at the end. It's not ideal,
    but It's better than not working code.
    [pwm.c]
2024-01-06 BUGFIX: Set pilot.is_enabled to 0 when pwm is set manually
    We should have already been doing that, but some commit that added
    command_handler must have lost the changes when rebasing.
    [furnace.c]
2024-02-04 Introduce logger, adjust "help" command
    Now the user can decide which output he wants to see on stdio.
    It is done in order to keep clear view over stdio.
    Current logs:
    "server" - tcp/ip server
    "thermocouple" - thermocouple
2024-02-04 furnace.c: send_stdio(): Bug fix
    If send_stdio() was called with some buffer and 0 as msg_len,
    it could have printf some garbage instead of nothing.
    Now it returns in case of msg_len = 0
    [furnace.c]
2024-02-04 Making ground for consteval-like utility
    C lacks in consteval functionality.
    This commit makes ground, and implements, a simple consteval-like utility.
    We compile and run on x86 native/consteval.c
    consteval.c's job will be to calculate some constants, and then
    write results to a header file.
    consteval_headers.h will stash calculated data as #define's
2024-02-04 Add "basic" log
    Now, user can get the same output on stdio, as over wifi connection.
    It is printing current temperature, current pwm and max pwm
    Additionally, some defines have been moved into basic_defines.h
2024-02-05 Adding info about auto status, and desired temperature
    We would like to use the HTTP utility, which enables us to
    control and monitor furnace from inside LAN.
2024-02-08 Adding magnetron handling software.
    I added handling magnetron pulse modulation and defines to
    make it fit both furnace and magnetron sputtering machine.
2024-02-08 Guarding unused help info with #if statements.
    We would like to not print help info about features that are
    unused.
2024-02-20 Fixing typo in pwm.c
    [pwm.c]
2024-02-20 bugfix: checking if args are valid ,but proceeding even if they're not
    Bug occured in command_handler, while handling log and pulse commands.
    [furnace.c]
2024-02-20 Adding water pump handling software
    We would like to steer water directly from pi pico controller
    using pwm so it can be steerable.
2024-02-20 BUGFIX: native/consteval.c
    snprintf returns the number of characters that would have been written
    if a sufficiently large buffer had been provided, EXCLUDING the terminating null
    character.
    However, we do need to count the '\0' in order to get properly formatted
    output
    [consteval.c]
2024-02-20 Adding support for max31865 driver for pt100 thermal sensor.
2024-02-20 BUGFIX: Fix misspelled CONFIG_WATER
    [furnace.c]
2024-03-03 BUGFIX: CONFIG_THERMO not works
    The GNU standard says:
    "Identifiers that are not macros, which are all considered to be the
    number zero. This allows you to write #if MACRO instead of #ifdef MACRO,
    if you know that MACRO, when defined, will always have a nonzero value.
    Function-like macros used without their function call parentheses are
    also treated as zero."
    According to that, pt100 and ktype were identifiers that are not macros,
    and was considered as 0.
    So we were always including, no matter what the user has passed.
    [furnace.c]
2024-03-09 Add CONFIG_FURNACE_FIRE_PIN to allow reconfiguration
    One of the PICO W boards with id 2422 4.15 got the standard
    FURNACE_FIRE_PIN=21 damaged and no longer works.
    Remapping there pin to FURNACE_FIRE_PIN=20 solves the issue for this
    board, therefore we add an easy way to do it.
    [furnace.c]
2024-03-09 Remove unused FURNACE_MAX318xx_RDY pin define
2024-03-10 pwm: lower the frequency to 8Hz
    We confirmed empirically that using "high" frequency as 40Hz is causing
    the resulting signal to be a complete nonsense. In practice we were
    seeing a long windows of even 5.5 seconds of constant, full power 230V
    sine followed by a similar, long windows of 0V. This behavior was
    causing the resistance wire to break frequently, making the furnace
    unusable. While in theory 8Hz should result in less smooth heating, we
    confirmed empirically, that in fact it's much more reliable.
    The whole power delivery circuitry needs to be and is being redesigned,
    but for now we ship a fairly easy work-around which allows us to use the
    furnace, while we wait for a better power del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
    [pwm.c]
2024-03-11 max31865: Remove RDY pin handling
    We never used it.
2024-03-15 Add CONFIG_MAX_PWM for configuring MAX_PWM
    Hotplate requires binary PWM, meaning MAX_PWM=1.
2024-03-31 Add CONFIG_FURNACE_DEADLINE_MS
    Used to control the speed of heating. We are having some issues with
    resistance wire breaking, which can be somewhat mitigated with slower
    rate of heating to account for inertia of the whole system.
    [furnace.c]
2024-03-31 Change default CONFIG_FURNACE_DEADLINE_MS from 15s to 21s
    We are having some problems with resistance wire breaking when around
    1000C temperatures. One way of mitigating this issue is to account for
    bigger inertia of the system and make the heating slower.
    We leave old value - 15s for hotplate, because it works just fine.
2024-03-31 Force complete shutdown of pwm for water when set to 0
    We thought that setting the pwm to WATER_OFFSET (40) is sufficient to
    not trigger the MOSFET driving the water pump, but in fact, sometimes
    pwm = 40, still results in it pumping water. If user set the pwm to 0 -
    we really set it to 0 now.
2024-04-02 Changing frequency of water pwm to 8Hz
    Due to too high frequency water motor took pwm as an average value of
    input_voltage*pwm/MAX_PWM. Becouse of the threshold voltage
    motor couldn't move. Lowering the frequency of pwm allows us to have
    the full resolution of it, without cutting off the lowest values.
    [furnace.c, pwm.c]
2024-04-07 Adding software to map pwm values with their max temperature
2024-04-12 Add ceiling_pwm for setting max pwm level at runtime
    Used when we want to be on auto pilot and prevent furnace from ever
    going above certain pwm level. Useful when working with high inertia
    systems.
    [common.h, consteval.c, furnace.c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]
2024-04-18 do_pilot_work: Do an early return in case auto is disabled or deadline not met
    Just a code formatting. This change is a no-op otherwise.
2024-05-26 Fix CONFIG_HOSTNAME propagation to CYW43 driver
    We were never setting CONFIG_HOSTNAME environment variable before
    calling configure_wifi.sh, which uses it to configure CMake project
    correctly, so that CYW43 get the constant.
2024-05-27 Change WATER_PIN from 12 to 9
    To make it work with the new PCB layout for the furnace.
2024-06-14 Add PCB directory with furnace files
    [pcb_furnace.pcbdoc, schemat_furnace.schdoc]
2025-02-03 Add linker script memmap.ld
    CMakeLists.txt: setting linker script to memmap.ld
    memmap.ld is copied from pico-sdk.
    File name is changed from memmap_default.ld to memmap.ld
2025-02-03 Introduce saving user config to flash memory
    Now, device is saving user config to non volatile memory.
    We are reserving space for user config in the device's
    flash memory.
    The main purpose of this utility, is to handle unexpected
    loss of electrical power.
    We want to let the device to boot itself up with the previous config.
